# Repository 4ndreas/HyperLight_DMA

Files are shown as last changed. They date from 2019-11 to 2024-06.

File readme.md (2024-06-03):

# Hyperlight LED Driver
STM32F407 based WS2811/12 Led driver with 16-channel DMA output

## variant 
* added custom variant with DMA interrupt function

## patched libraies are
* Artnet
* Ethernet
	* Changed SPI speed
	* Port so 2 with increases the buffer in the W5500 chip per port to 8k
* Adafruit_SSD1306
	* Display size to 128x64
	
* Overrides for ST SPI Hal Code beed as compile options: -include "<absolute-src-path>/make_weak.h"

## ToDo

* Improvement for
    * better bit sorting
    * setLED function
    * setSnakeLED
    * better solution for other color modes

* Webserver Config for
    * Color Mode
    * offset 
    * Snake Wireing
    * FPS Counter

* USB test
* SD-Card 
* better Webserver with SD card or the website.h methode
* DMX out

## How to Install

```
https://github.com/stm32duino/BoardManagerFiles/raw/master/STM32/package_stm_index.json
```

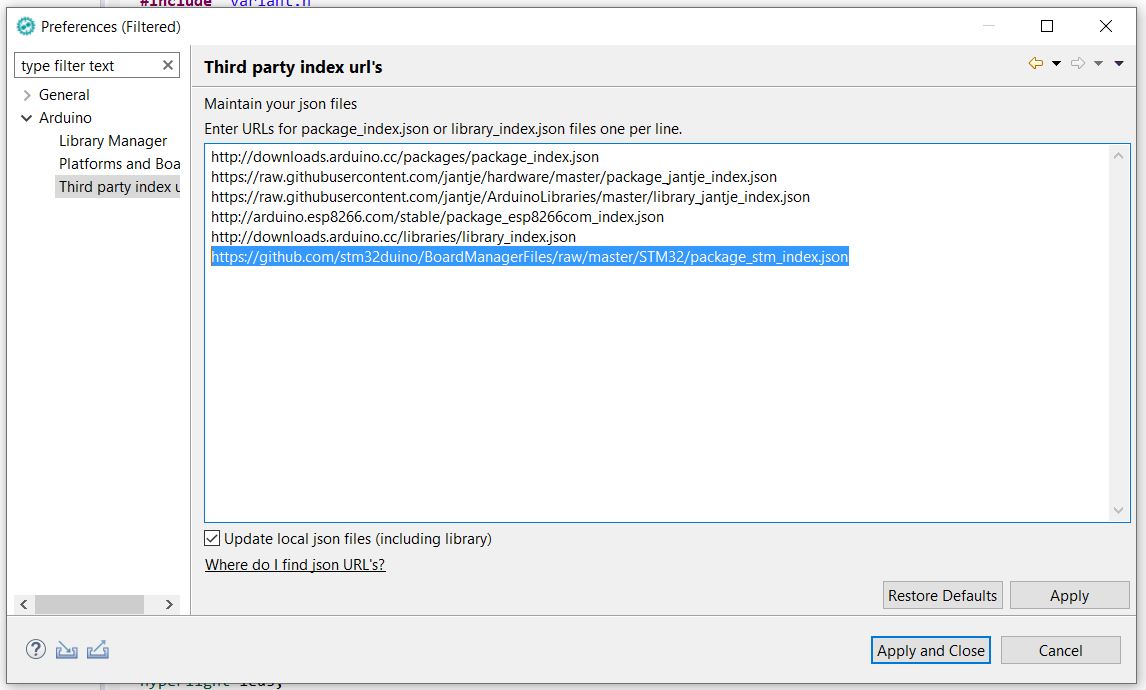
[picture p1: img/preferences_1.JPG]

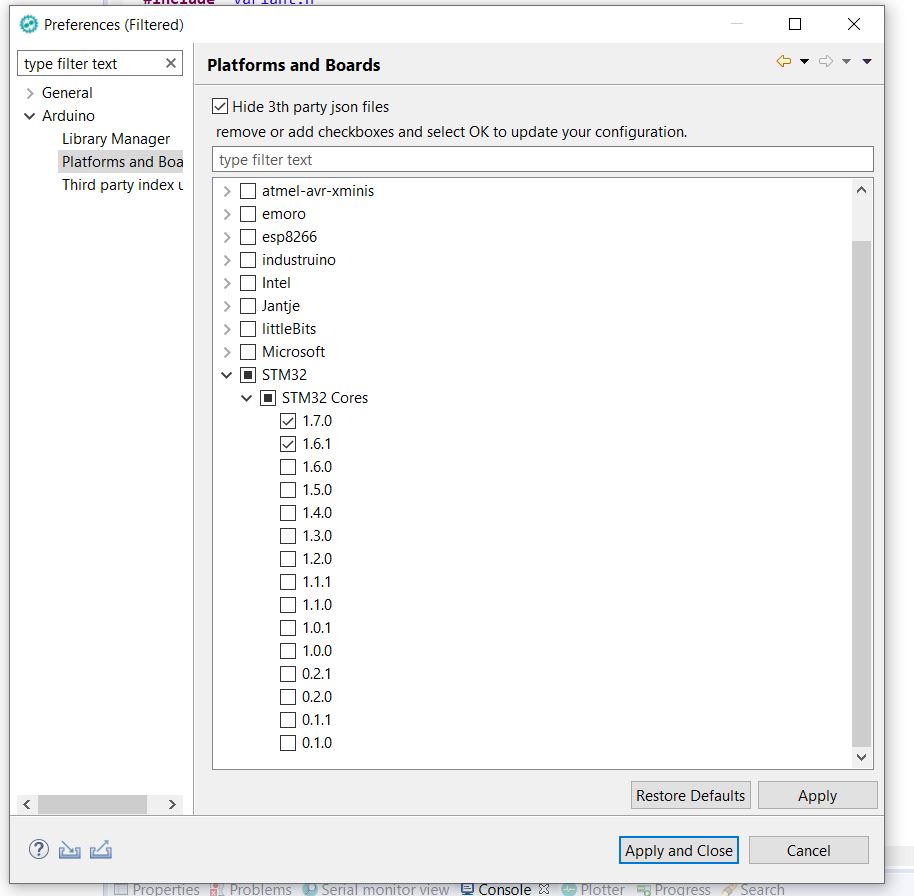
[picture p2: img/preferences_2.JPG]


### Adding a new board variant 

Path to the boards:

coppy the variants\Hyperlight folder in the package dir:

```
\Sloeber\arduinoPlugin\packages\STM32\hardware\stm32\1.7.0\variants\Hyperlight
```
or if the plain arduino IDE is used in  
```
.user\AppData\Local\Arduino15\packages\STM32\hardware\stm32\1.7.0\variants
```

Setting for the board:

Optimize: "Smallest(-Os default)"

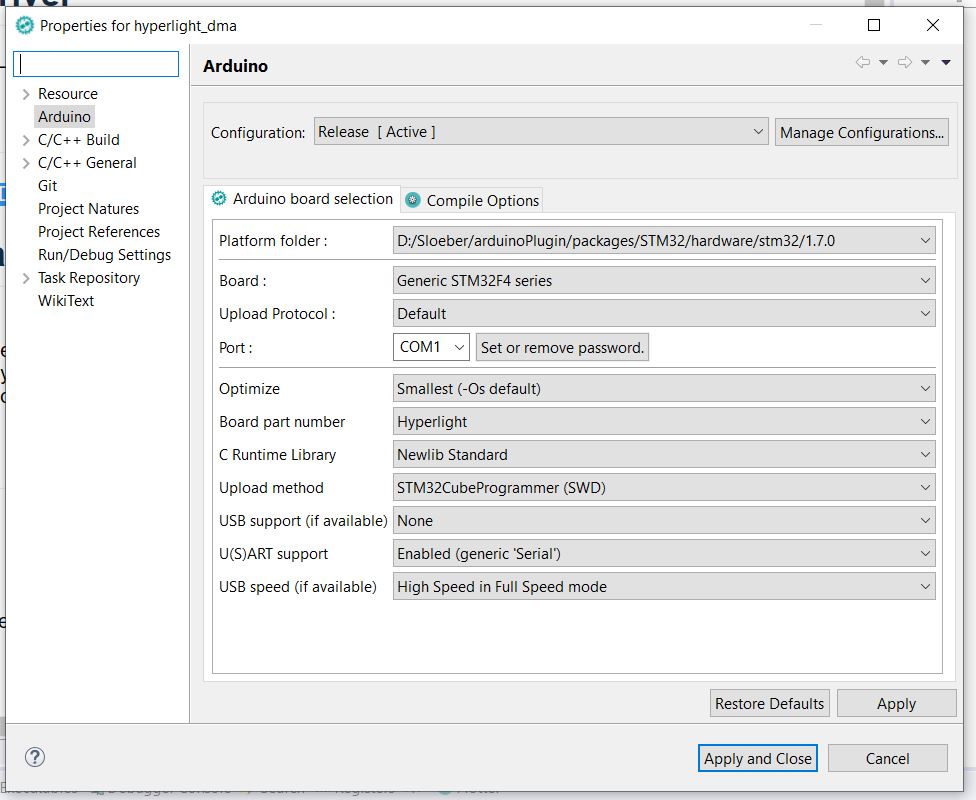
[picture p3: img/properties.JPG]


Add make_weak to "compiler Options"
```
-include "C:\Users\ahoel\Documents\sloeber-workspace\hyperlight_dma\make_weak.h"
```
![alt text][properties2]

### How to Debug
See the wiki form the STM32 Core
https://github.com/stm32duino/wiki/wiki/How-to-debug

Download sloeber-IDE form 
http://eclipse.baeyens.it/index.shtml

Change Target to:
```
-s "${openocd_path}/../scripts" -f interface/stlink-v2-1.cfg -f target/stm32f4x.cfg
```
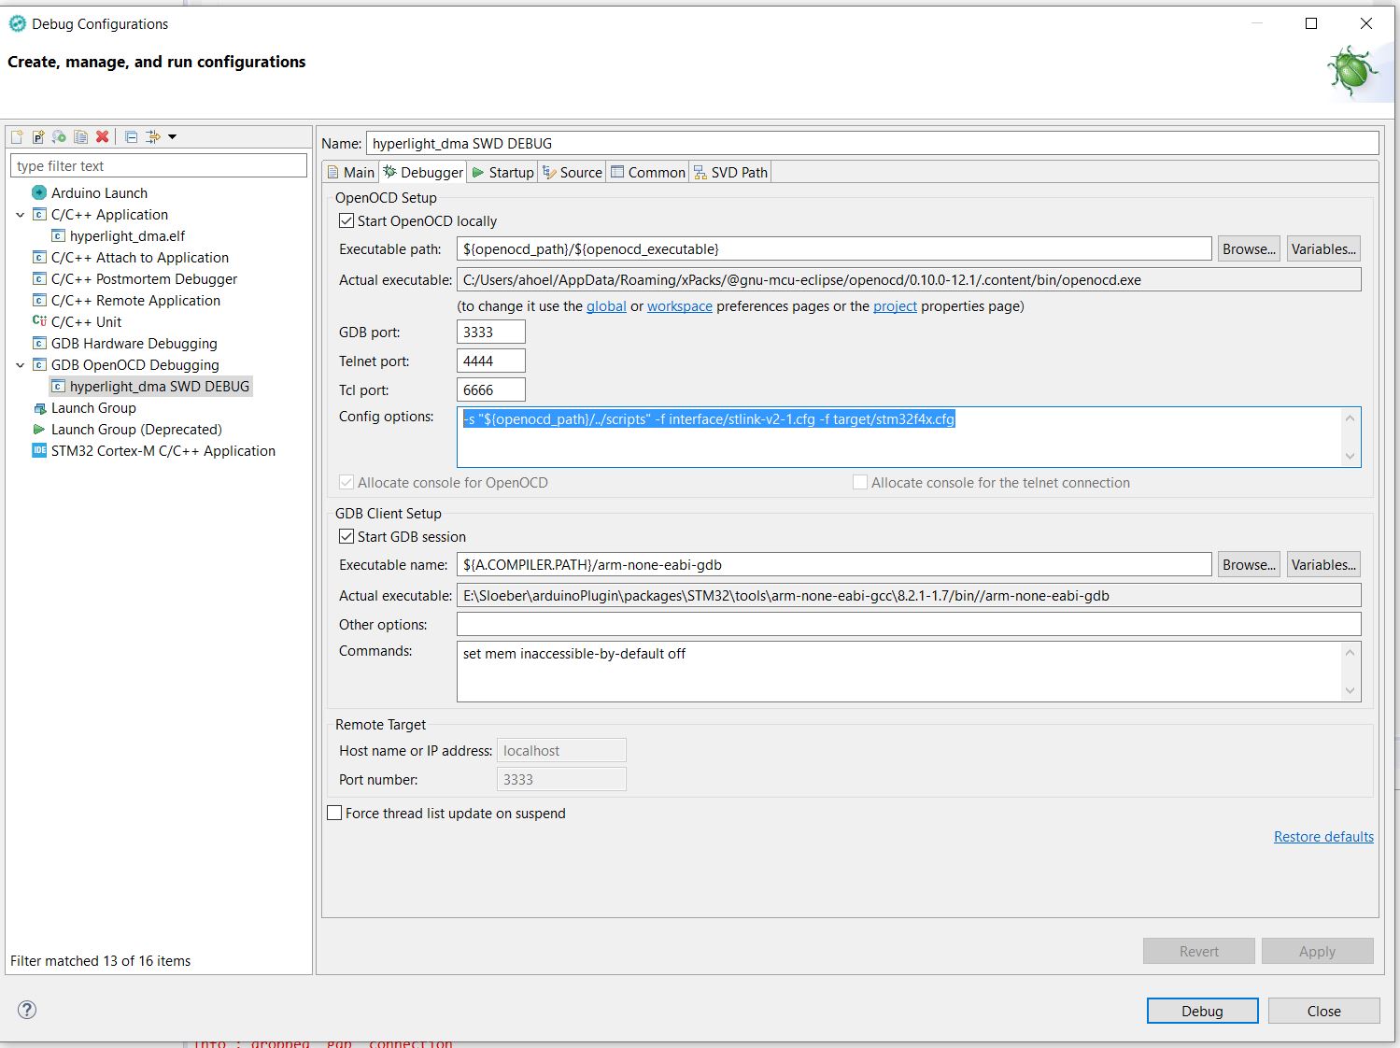
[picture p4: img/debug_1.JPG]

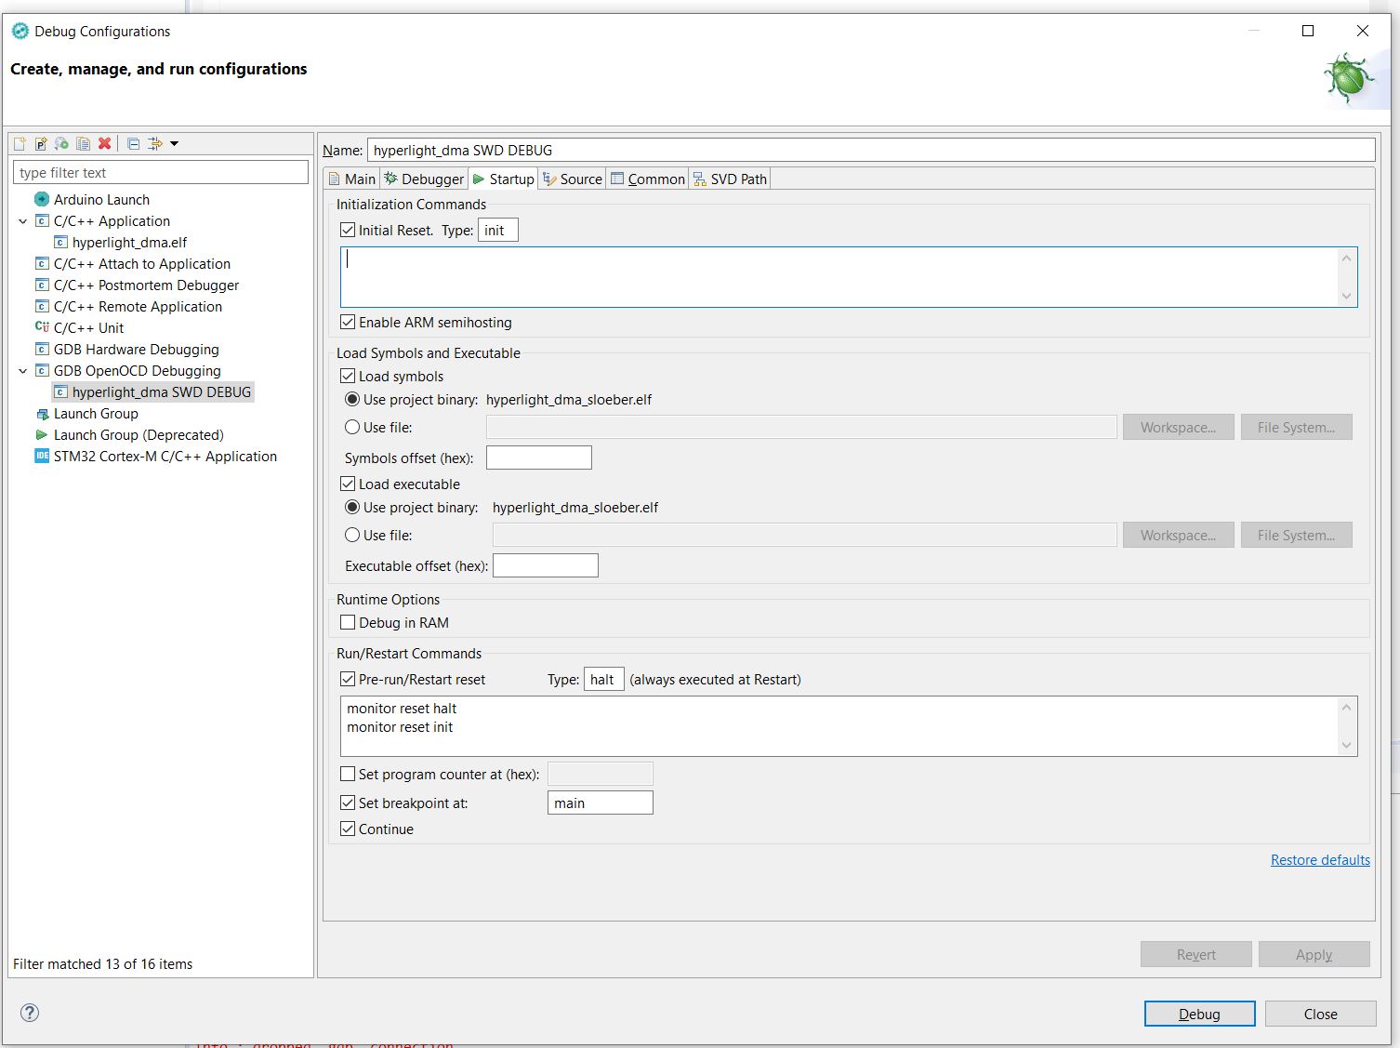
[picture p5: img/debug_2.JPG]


[preferences1]: img/preferences_1.JPG "Settings URL for STM32Core"
[preferences2]: img/preferences_2.JPG "Settings URL for STM32Core"
[properties]: img/properties.JPG "properties of the arduino ide"
[debug1]: img/debug_1.JPG "Settings URL for OCD Debugging"
[debug2]: img/debug_2.JPG "Settings URL for OCD Debugging"

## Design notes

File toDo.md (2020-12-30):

## ToDos

- optimiertes paralleles setzen von allen strips gleichzeitig
- SPI recieve code durchgehen ob optimieren

### Knownn Bugs

- packet los bei % 2 frame bei 255
-- mögliches problem mit nur beil 1 bit setzten effekt
-- maximaler zyklus für Bit sort setzten

### Nice to have

- Webserver wieder einbauen 
- Interrupt leitung Ethernet script.
- Profiling mit Artnet Sequenz number.
- oled display updaten.
- Testpattern zum geräte testen.

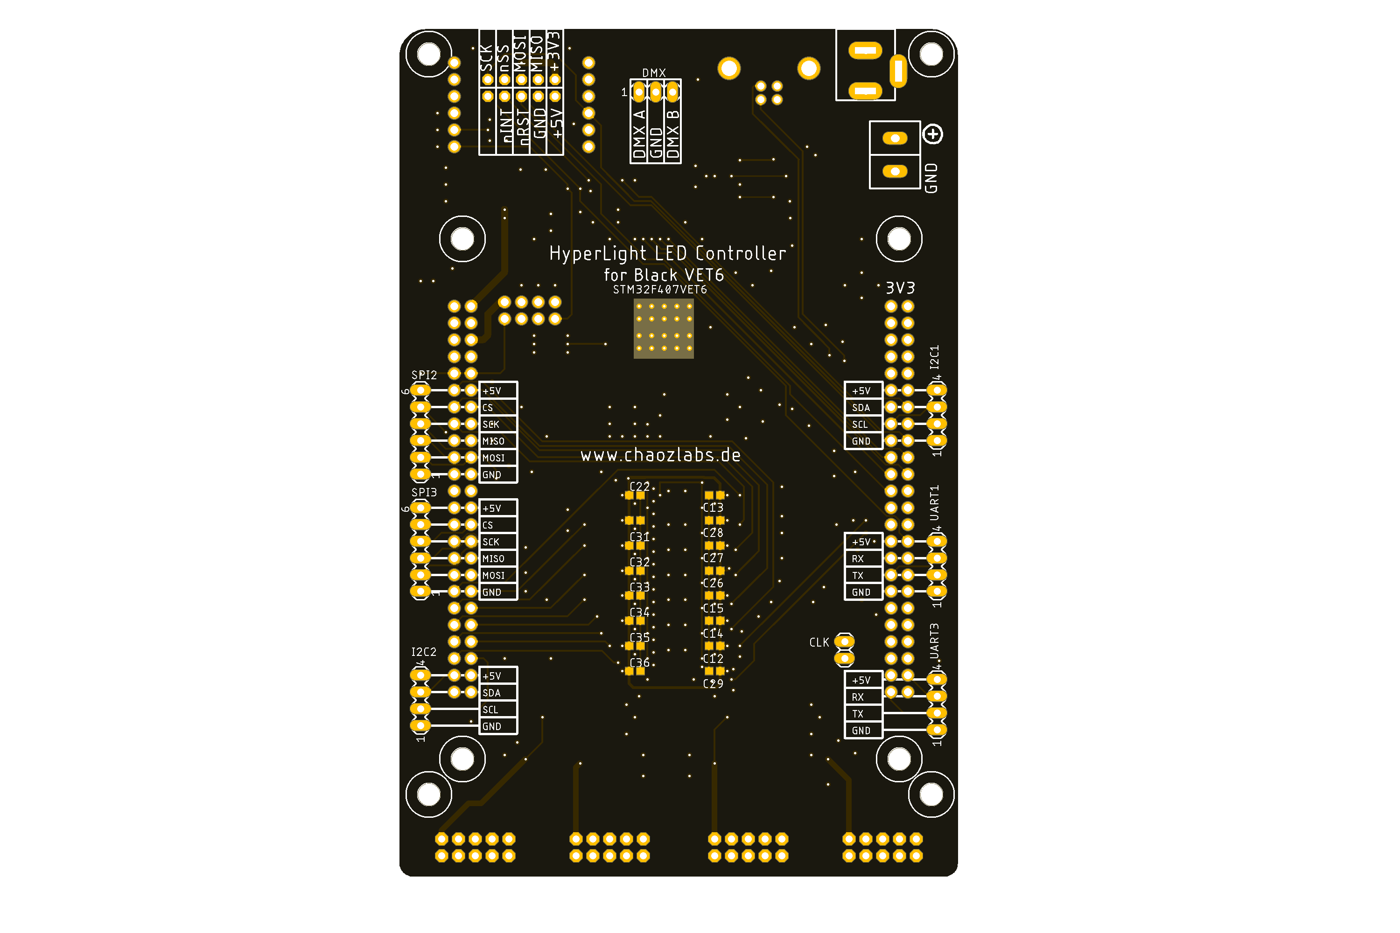
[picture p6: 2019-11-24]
hardware/rev1/HyperLight_S_rev1.0_Bottom.png

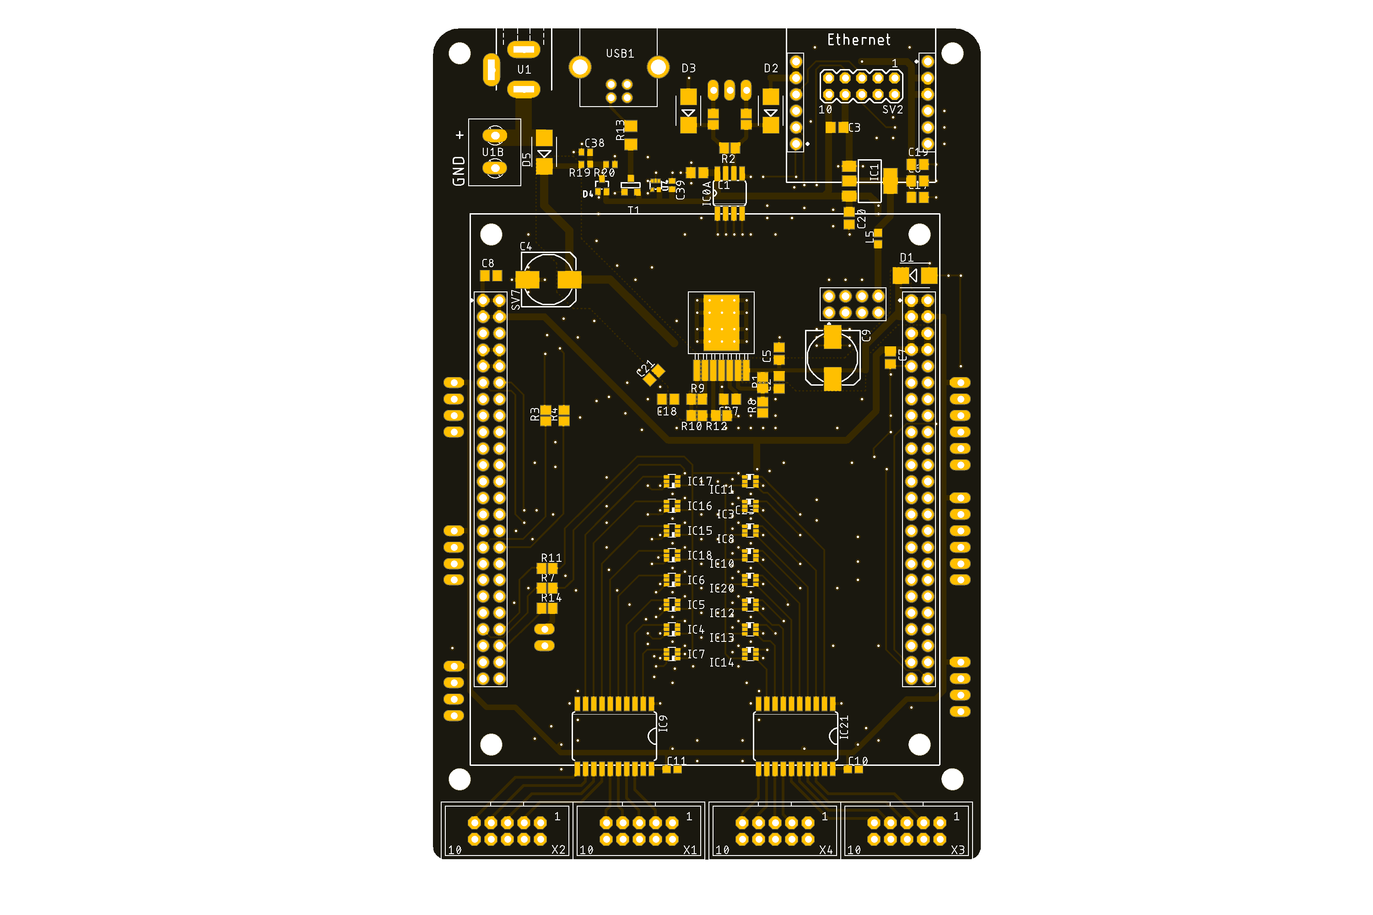
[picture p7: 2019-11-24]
hardware/rev1/HyperLight_S_rev1.0_Top.png

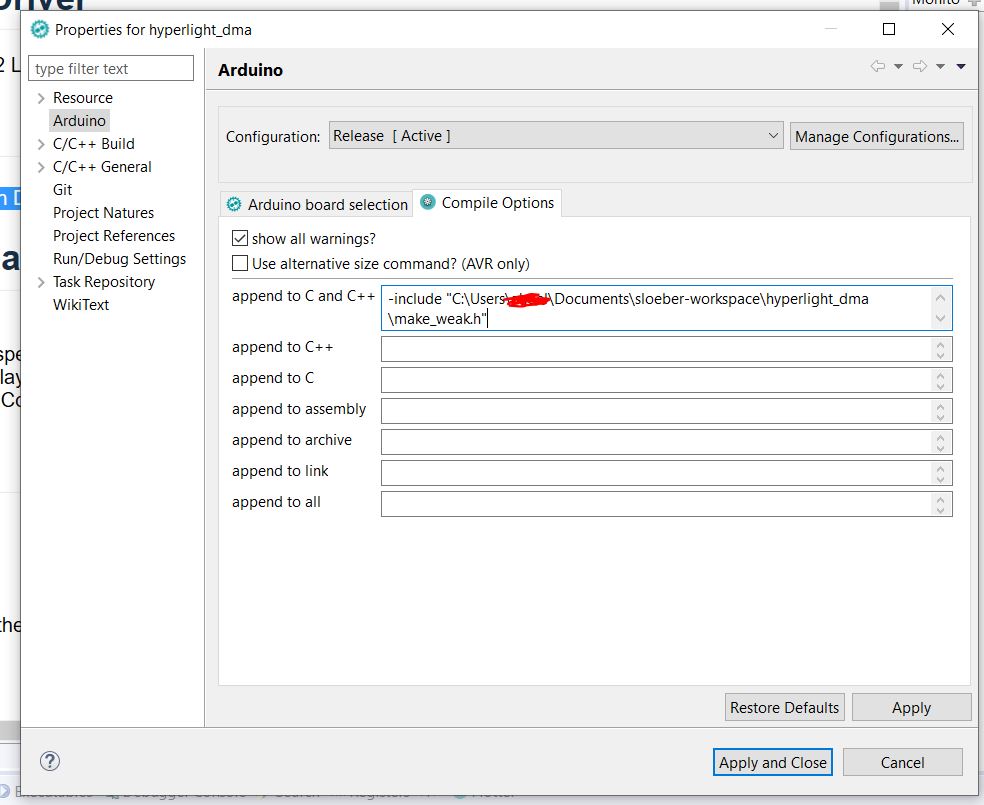
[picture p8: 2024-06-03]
img/properties2.JPG

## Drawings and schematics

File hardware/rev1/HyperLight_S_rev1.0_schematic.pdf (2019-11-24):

# GND ⁺³V³

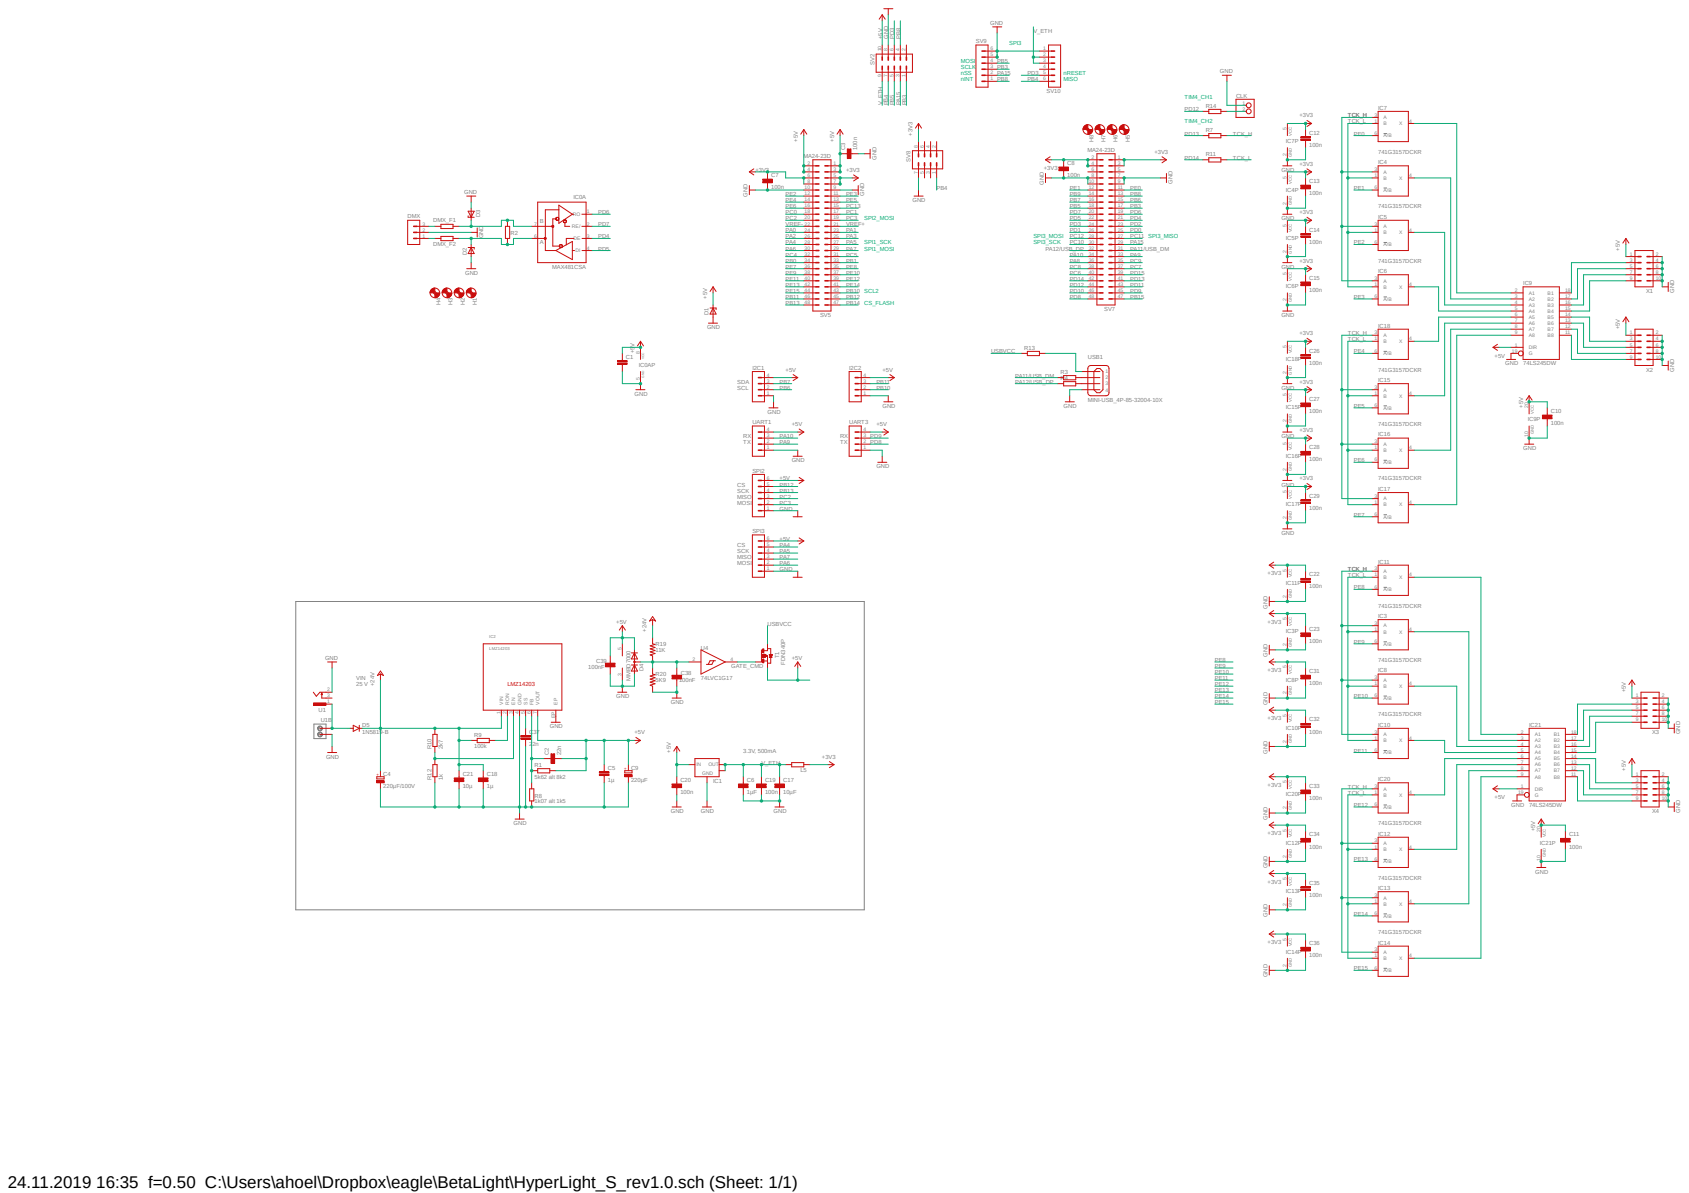
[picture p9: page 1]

IC7 2 5 GND VCC IC7P 2 5 GND VCC IC4P 2 5 GND VCC IC5P 2 5 GND VCC IC6P

GND
IC18 2 5 GND VCC IC18P 2 5 GND VCC IC15P 2 5 GND VCC IC16P 2 5 GND VCC IC17P

IC20 ² ⁵ GND VCC IC11P 2 5 GND VCC IC3P 2 5 GND VCC IC8P 2 5 GND VCC IC10P 2 5 GND VCC IC20P 2 5 GND VCC IC12P 2 5 GND VCC IC13P 2 5 GND VCC IC14P
100n GND GND GND GND GND GND GND GND +3V3

24.11.2019 16:35 f=0.50 C:\Users\ahoel\Dropbox\eagle\BetaLight\HyperLight_S_rev1.0.sch (Sheet: 1/1)

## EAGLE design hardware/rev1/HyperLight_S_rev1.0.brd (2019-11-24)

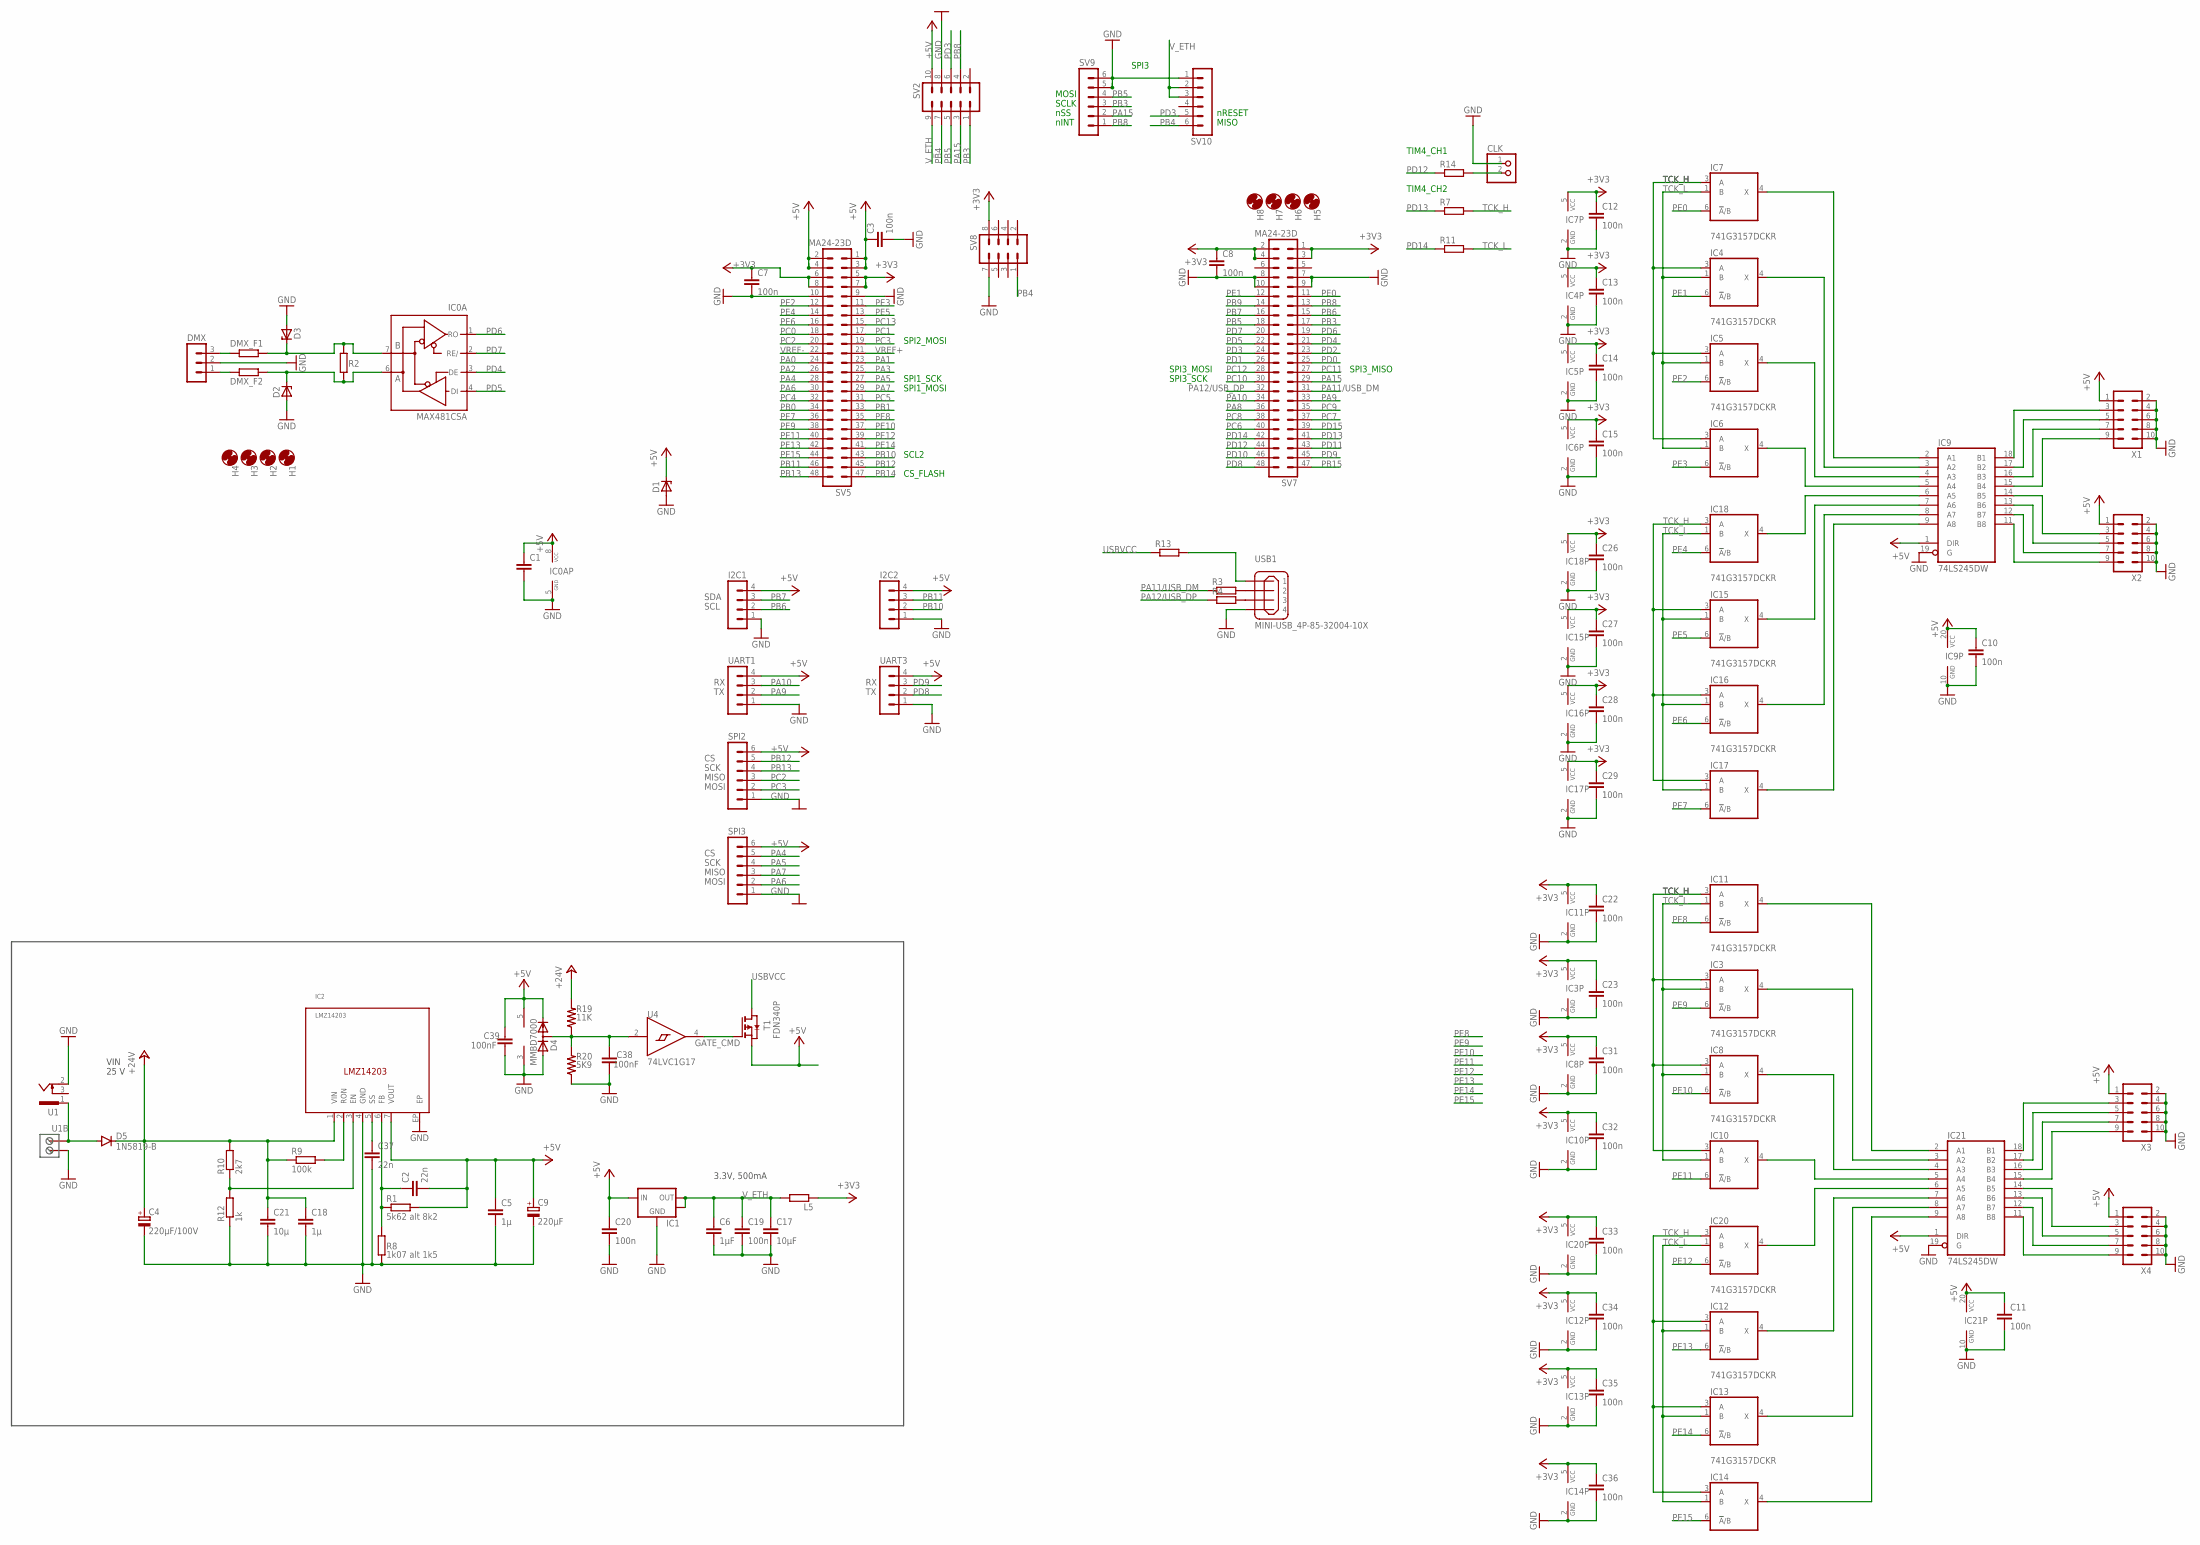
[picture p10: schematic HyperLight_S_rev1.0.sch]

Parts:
C1: C-EUC0805; C0805
C2, C37: 22n; C0805
C3, C7, C8, C19, C20: 100n; C0805
C4: 220µF/100V; 153CLV-0810
C5, C18: 1µ; C0805
C6: 1µF; C0805
C9: 220µF; 153CLV-0810
C10, C11, C12, C13, C14, C15, C22, C23, C26, C27, C28, C29, C31, C32, C33, C34, C35, C36: 100n; C0603
C17: 10µF; C0805
C21: 10µ; C0805
C38, C39: 100nF; C0402
CLK: PINHD-1X2; 1X02
D1, D2, D3: ZENER-DIODESMB; SMB
D4: MMBD7000; SC70-3-R
D5: 1N5819-B; SMB
DMX: MA03-1
DMX_F1, DMX_F2: R-EU_R0805; R0805
H1, H2, H3, H4, H5, H6, H7, H8: MOUNT-HOLE3.2; 3,2
I2C1, I2C2: MA04-1
IC0A: MAX481CSA; SO08
IC1: LM1117; SOT223
IC2: LMZ14203; TO-PMOD
IC3, IC4, IC5, IC6, IC7, IC8, IC10, IC11, IC12, IC13, IC14, IC15, IC16, IC17, IC18, IC20: 741G3157DCKR; DCK_R-PDSO-G6
IC9, IC21: 74LS245DW; SO20W
L5: R-EU_R0603; R0603
R1: 5k62 alt 8k2; R0805
R2, R3, R4, R7, R11, R14: R-EU_R0805; R0805
R8: 1k07 alt 1k5; R0805
R9: 100k; R0805
R10: 2k7; R0805
R12: 1k; R0805
R13: R-EU_R1206; R1206
R19: 11K; R0402
R20: 5K9; R0402
SPI2, SPI3: MA06-1
SV2: MA05-2
SV5, SV7: MA24-23D; HDRVR48W64P254_2X24_6096X508X762B
SV8: MA04-2MALE_3D; HDRV8W64P254_2X4_1016X508X838B
SV9, SV10: MA06-1FEMALE_3D; HDRVR6W64P254_1X6_1524X254X762B
T1: FDN340P; SOT-23
U1: 733980-62
U1B: RIACON101-02
U4: 74LVC1G17; SOT-553
UART1, UART3: MA04-1
USB1: MINI-USB_4P-85-32004-10X; 85-32004-10X
X1, X2, X3, X4: MA05-2MA05-2S; MA05-2S

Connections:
+3V3: C7.1, C8.1, C12.1, C13.1, C14.1, C15.1, C22.1, C23.1, C26.1, C27.1, C28.1, C29.1, C31.1, C32.1, C33.1, C34.1, C35.1, C36.1, IC3.5 (VCC), IC4.5 (VCC), IC5.5 (VCC), IC6.5 (VCC), IC7.5 (VCC), IC8.5 (VCC), IC10.5 (VCC), IC11.5 (VCC), IC12.5 (VCC), IC13.5 (VCC), IC14.5 (VCC), IC15.5 (VCC), IC16.5 (VCC), IC17.5 (VCC), IC18.5 (VCC), IC20.5 (VCC), L5.1, SV5.5, SV5.6, SV5.7, SV5.8, SV7.1, SV7.2, SV7.3, SV7.4, SV8.8
+5V: C1.1, C2.2, C3.1, C5.1, C9.+, C10.1, C11.1, C20.1, C39.2, D1.C, D4.2 (C), I2C1.4, I2C2.4, IC0A.8 (VCC), IC1.3 (IN), IC2.7 (VOUT), IC9.1 (DIR), IC9.20 (VCC), IC21.1 (DIR), IC21.20 (VCC), R1.2, SPI2.6, SPI3.6, SV2.10, SV5.1, SV5.2, SV5.3, SV5.4, T1.2 (S), U4.5 (VCC), UART1.4, UART3.4, X1.1, X2.1, X3.1, X4.1
+24V: C4.+, C18.1, C21.1, D5.C, IC2.1 (VIN), R9.1, R10.2, R19.2
CMP: C38.2, D4.3 (AC), R19.1, R20.2, U4.2 (A)
GATE_CMD: T1.3 (G), U4.4 (Y)
GND: C1.2, C3.2, C4.-, C5.2, C6.2, C7.2, C8.2, C9.-, C10.2, C11.2, C12.2, C13.2, C14.2, C15.2, C17.2, C18.2, C19.2, C20.2, C21.2, C22.2, C23.2, C26.2, C27.2, C28.2, C29.2, C31.2, C32.2, C33.2, C34.2, C35.2, C36.2, C37.2, C38.1, C39.1, CLK.1, D1.A, D2.A, D3.A, D4.1 (A), DMX.2, I2C1.1, I2C2.1, IC0A.5 (GND), IC1.1 (GND), IC2.4 (GND), IC2.EP, IC3.2 (GND), IC4.2 (GND), IC5.2 (GND), IC6.2 (GND), IC7.2 (GND), IC8.2 (GND), IC9.10 (GND), IC9.19 (G), IC10.2 (GND), IC11.2 (GND), IC12.2 (GND), IC13.2 (GND), IC14.2 (GND), IC15.2 (GND), IC16.2 (GND), IC17.2 (GND), IC18.2 (GND), IC20.2 (GND), IC21.10 (GND), IC21.19 (G), R8.1, R12.1, R20.1, SPI2.1, SPI3.1, SV2.8, SV5.9, SV5.10, SV7.7, SV7.8, SV7.9, SV7.10, SV8.7, SV9.5, SV9.6, SV10.1, U1.2, U1B.P$2, U4.3 (GND), UART1.1, UART3.1, USB1.4, X1.2, X1.4, X1.6, X1.8, X1.10, X2.2, X2.4, X2.6, X2.8, X2.10, X3.2, X3.4, X3.6, X3.8, X3.10, X4.2, X4.4, X4.6, X4.8, X4.10
unnamed: IC7.4 (X), IC9.2 (A1)
unnamed: IC5.4 (X), IC9.4 (A3)
unnamed: R3.2, USB1.2
unnamed: IC6.4 (X), IC9.5 (A4)
unnamed: IC4.4 (X), IC9.3 (A2)
unnamed: IC9.18 (B1), X1.3
unnamed: D3.C, DMX_F1.1, IC0A.7 (B), R2.2
unnamed: D2.C, DMX_F2.1, IC0A.6 (A), R2.1
unnamed: R4.2, USB1.3
unnamed: C2.1, IC2.6 (FB), R1.1, R8.2
unnamed: IC9.6 (A5), IC18.4 (X)
unnamed: IC2.2 (RON), R9.2
unnamed: IC11.4 (X), IC21.2 (A1)
unnamed: C37.1, IC2.5 (SS)
unnamed: IC9.9 (A8), IC17.4 (X)
unnamed: IC2.3 (EN), R10.1, R12.2
unnamed: D5.A, U1.1, U1B.P$1
unnamed: IC9.8 (A7), IC16.4 (X)
unnamed: IC9.7 (A6), IC15.4 (X)
unnamed: IC9.17 (B2), X1.5
unnamed: IC9.16 (B3), X1.7
unnamed: IC9.15 (B4), X1.9
unnamed: DMX.3, DMX_F1.2
unnamed: DMX.1, DMX_F2.2
unnamed: IC8.4 (X), IC21.4 (A3)
unnamed: IC10.4 (X), IC21.5 (A4)
unnamed: IC20.4 (X), IC21.6 (A5)
unnamed: IC14.4 (X), IC21.9 (A8)
unnamed: IC13.4 (X), IC21.8 (A7)
unnamed: IC12.4 (X), IC21.7 (A6)
unnamed: IC3.4 (X), IC21.3 (A2)
unnamed: R13.2, USB1.1
unnamed: CLK.2, R14.2
unnamed: IC21.18 (B1), X3.3
unnamed: IC21.17 (B2), X3.5
unnamed: IC21.16 (B3), X3.7
unnamed: IC21.15 (B4), X3.9
unnamed: IC21.14 (B5), X4.3
unnamed: IC21.13 (B6), X4.5
unnamed: IC21.12 (B7), X4.7
unnamed: IC21.11 (B8), X4.9
unnamed: IC9.14 (B5), X2.3
unnamed: IC9.13 (B6), X2.5
unnamed: IC9.12 (B7), X2.7
unnamed: IC9.11 (B8), X2.9
PA0: SV5.24
PA1: SV5.23
PA2: SV5.26
PA3: SV5.25
PA4: SPI3.5, SV5.28
PA5: SPI3.4, SV5.27
PA6: SPI3.2, SV5.30
PA7: SPI3.3, SV5.29
PA8: SV7.36
PA9: SV7.33, UART1.2
PA10: SV7.34, UART1.3
PA11/USB_DM: R3.1, SV7.31
PA12/USB_DP: R4.1, SV7.32
PA15: SV2.3, SV7.29, SV9.2
PB0: SV5.34
PB1: SV5.33
PB3: SV2.1, SV7.17, SV9.3
PB4: SV2.7, SV8.1, SV10.6
PB5: SV2.5, SV7.18, SV9.4
PB6: I2C1.2, SV7.15
PB7: I2C1.3, SV7.16
PB8: SV2.4, SV7.13, SV9.1
PB9: SV7.14
PB10: I2C2.2, SV5.43
PB11: I2C2.3, SV5.46
PB12: SPI2.5, SV5.45
PB13: SPI2.4, SV5.48
PB14: SV5.47
PB15: SV7.47
PC0: SV5.18
PC1: SV5.17
PC2: SPI2.3, SV5.20
PC3: SPI2.2, SV5.19
PC4: SV5.32
PC5: SV5.31
PC6: SV7.40
PC7: SV7.37
PC8: SV7.38
PC9: SV7.35
PC10: SV7.30
PC11: SV7.27
PC12: SV7.28
PC13: SV5.15
PD0: SV7.25
PD1: SV7.26
PD2: SV7.23
PD3: SV2.6, SV7.24, SV10.5
PD4: IC0A.3 (DE), SV7.21
PD5: IC0A.4 (DI), SV7.22
PD6: IC0A.1 (RO), SV7.19
PD7: IC0A.2 (RE/), SV7.20
PD8: SV7.48, UART3.2
PD9: SV7.45, UART3.3
PD10: SV7.46
PD11: SV7.43
PD12: R14.1, SV7.44
PD13: R7.1, SV7.41
PD14: R11.1, SV7.42
PD15: SV7.39
PE0: IC7.6 (!A!/B), SV7.11
PE1: IC4.6 (!A!/B), SV7.12
PE2: IC5.6 (!A!/B), SV5.12
PE3: IC6.6 (!A!/B), SV5.11
PE4: IC18.6 (!A!/B), SV5.14
PE5: IC15.6 (!A!/B), SV5.13
PE6: IC16.6 (!A!/B), SV5.16
PE7: IC17.6 (!A!/B), SV5.36
PE8: IC11.6 (!A!/B), SV5.35
PE9: IC3.6 (!A!/B), SV5.38
PE10: IC8.6 (!A!/B), SV5.37
PE11: IC10.6 (!A!/B), SV5.40
PE12: IC20.6 (!A!/B), SV5.39
PE13: IC12.6 (!A!/B), SV5.42
PE14: IC13.6 (!A!/B), SV5.41
PE15: IC14.6 (!A!/B), SV5.44
TCK_H: IC3.3 (A), IC4.3 (A), IC5.3 (A), IC6.3 (A), IC7.3 (A), IC8.3 (A), IC10.3 (A), IC11.3 (A), IC12.3 (A), IC13.3 (A), IC14.3 (A), IC15.3 (A), IC16.3 (A), IC17.3 (A), IC18.3 (A), IC20.3 (A), R7.2
TCK_L: IC3.1 (B), IC4.1 (B), IC5.1 (B), IC6.1 (B), IC7.1 (B), IC8.1 (B), IC10.1 (B), IC11.1 (B), IC12.1 (B), IC13.1 (B), IC14.1 (B), IC15.1 (B), IC16.1 (B), IC17.1 (B), IC18.1 (B), IC20.1 (B), R11.2
USBVCC: R13.1, T1.1 (D)
VREF+: SV5.21
VREF-: SV5.22
V_ETH: C6.1, C17.1, C19.1, IC1.2 (OUT), IC1.4 (PAD), L5.2, SV2.9, SV10.2, SV10.3

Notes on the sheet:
MOSI
SCLK
nSS
nINT
nRESET
MISO
SPI1_MOSI
SPI1_SCK
SPI3_SCK
SPI3_MOSI
SPI3_MISO
SPI2_MOSI
SCL2
CS_FLASH
SPI3
TIM4_CH1
TIM4_CH2
25 V
VIN
3.3V, 500mA
SDA
SCL
SCK

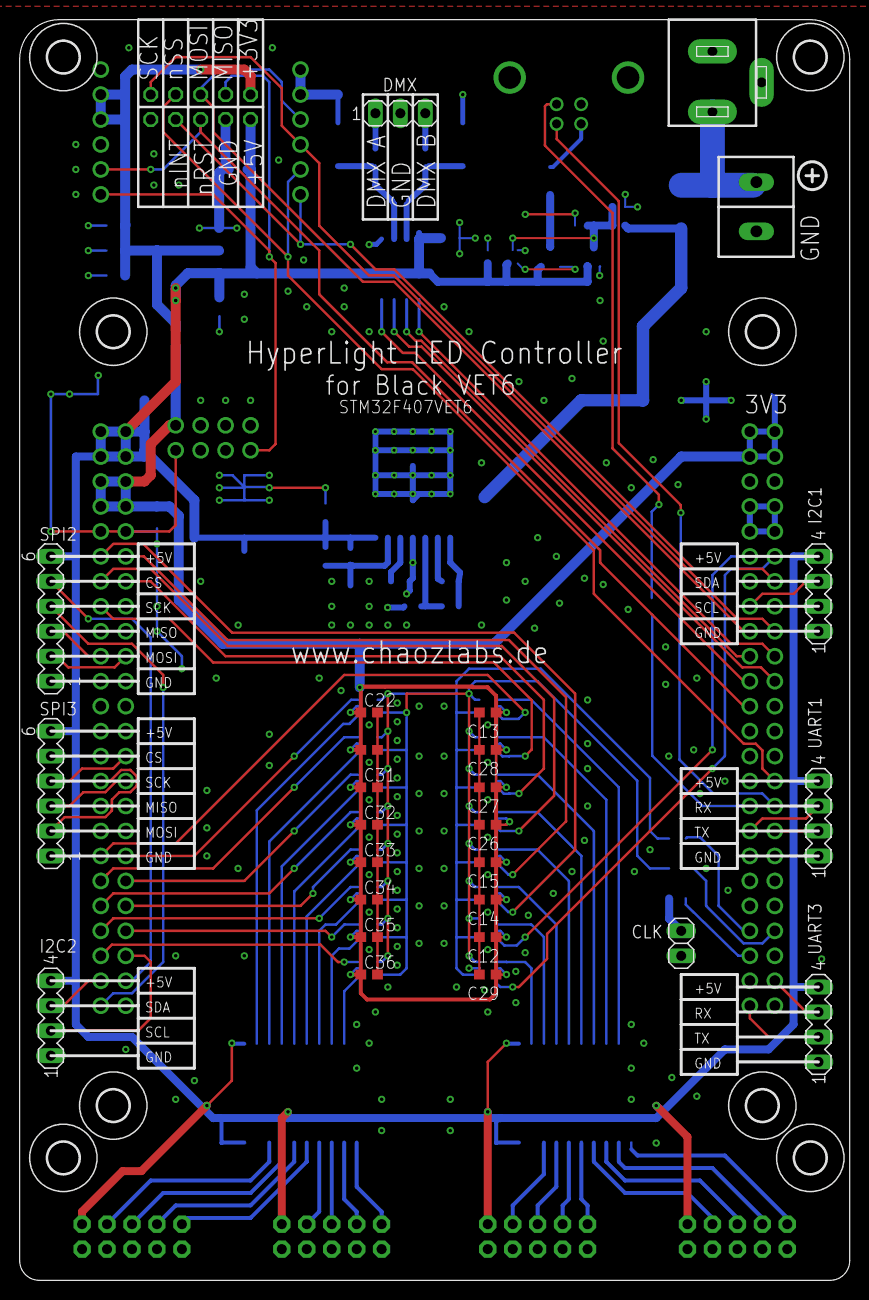
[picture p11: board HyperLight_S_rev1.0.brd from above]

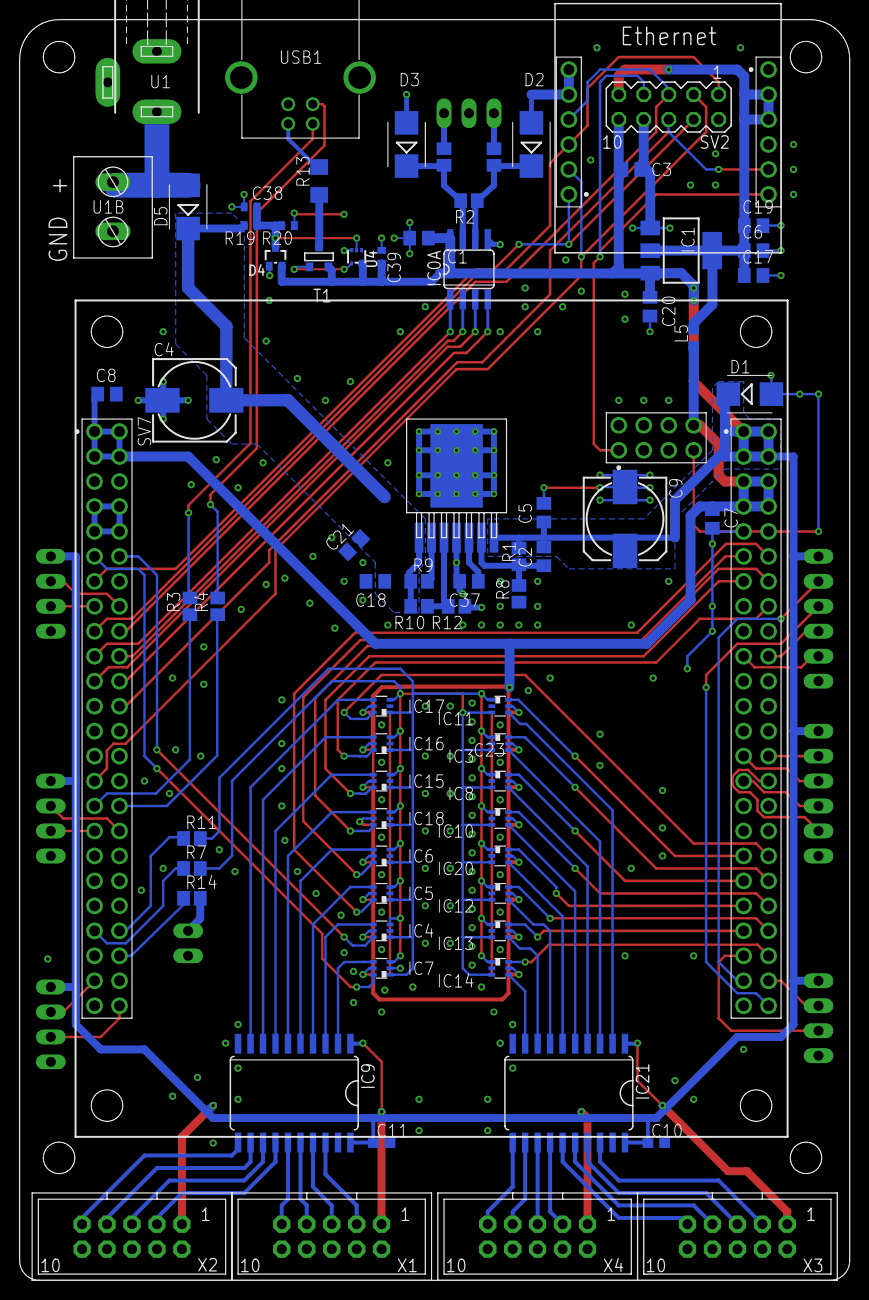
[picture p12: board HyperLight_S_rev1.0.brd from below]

Board: 2 copper layers, 84.5 x 128.3 mm, 109 parts (77 on the bottom side), 102 nets.

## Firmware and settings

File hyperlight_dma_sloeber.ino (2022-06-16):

#define ARCH_STM32

#include "Arduino.h"
#include "variant.h"
#include "pin_config.h"
#include <SPI.h>
#include <SPIMemory.h>
#include <IWatchdog.h>
#include <FlashStorage_STM32.h>
#include <Math.h>
#include "BufferedArtnet.h"
#include "hyperlight.h"
#include "F4DMXSerial.h"
#include "helper.h"


//#define USE_WEBSERVER
#define USE_OLED
#define USE_BUTTONS
#define USE_DMX
//#define USE_LCD
//#define USE_FLASH
#define USE_EEPROM
//#define USE_WATCHDOG


#define IP_ENDING 22


#ifdef USE_DMX
// To do
#define DMX_UNI 65
F4DMXSerial dmxOUT;
#endif

#ifdef USE_BUTTONS
// Button1
// Button2
#endif

#ifdef USE_OLED
#include <Wire.h>
#include <Adafruit_GFX.h>
#include <Adafruit_SSD1306.h>
#include <Fonts/FreeSansBold9pt7b.h>
#define OLED_RESET -1
Adafruit_SSD1306 display(OLED_RESET);
#endif


#ifdef USE_LCD
#include <wire.h>
//#include <liquidcrystal_i2c.h>
#include <LiquidCrystal_I2C.h>
// Set the LCD address to 0x27 for a 16 chars and 2 line display
LiquidCrystal_I2C lcd(0x27, 16, 2);
#endif


#ifdef USE_WEBSERVER
#include "website.h"

// Initialize the Ethernet server library
EthernetServer server(80);
#endif

struct sConfig sysConfig;

#ifdef USE_FLASH
	SPIFlash flash(SPI_FLASH_CS);
#endif




#define CONFIG_UNI 66
BufferedArtnet<67> artnet;
//BufferedArtnet<33> artnet;
hyperlight leds;

#define LED_OFFSET 1


byte ip[] = {10, 39, 0, IP_ENDING};
#define CONCAT(m, n) m ## n
#define HEXIFY(x) CONCAT(0x, x)
byte mac[] = {0x04, 0xE9, 0xE5, HEXIFY(IP_ENDING), 0x69, 0xEC};

// sets artnet timeout in ms (only for show)
#define INACTIVITY_TIMEOUT 1000
IPAddress remoteArd;

void setup() {

#ifdef USE_WATCHDOGUSE_WATCHDOG
  if (IWatchdog.isReset(true)) {
		  // to do monitor resets by watchdog
  }

  IWatchdog.begin(4000000);
#endif

  // Hardware Serial1 for debug out
  Serial.begin(115200);
  Serial.println("init");

  Serial.println("My IP:");
  Serial.print(ip[0], DEC);Serial.print(".");
  Serial.print(ip[1], DEC);Serial.print(".");
  Serial.print(ip[2], DEC);Serial.print(".");
  Serial.print(ip[3], DEC);Serial.println("");

  leds.begin();



#ifdef USE_WEBSERVER
  server.begin();
#endif

#ifdef USE_OLED

  Wire.setSDA(I2C1_SDA_PIN);
  Wire.setSCL(I2C1_SCL_PIN);


  display.begin(SSD1306_SWITCHCAPVCC, 0x3C);  // initialize with the I2C addr 0x3D (for the 128x64)
  // init done
  display.clearDisplay();
  updateDisplay();
#endif


#ifdef USE_LCD

  Wire.setSDA(I2C1_SDA_PIN);
  Wire.setSCL(I2C1_SCL_PIN);
  lcd.begin(16,2);
  lcd.init();
  lcd.backlight();
  lcd.clear();


  lcd.setCursor(0, 0);
  lcd.print("Hyperlight");
  lcd.setCursor(0, 1);
  lcd.print("init");
  lcd.display();

#endif


#ifdef USE_DMX
  dmxOUT.begin();
  delay(1);
  dmxOUT.Send_Packet();
#endif

#ifdef USE_FLASH
  flash.begin();
  readConfig();
#endif

#ifdef USE_EEPROM
  //Serial.print(F("\nStart FlashStoreAndRetrieve on ")); Serial.println(BOARD_NAME);
  Serial.println(FLASH_STORAGE_STM32_VERSION);

  Serial.print("EEPROM length: ");
  Serial.println(EEPROM.length());

  readConfig();

#else
  defaultConfig();
#endif


  pinMode(ETH_RST_PIN, OUTPUT);

  digitalWrite(ETH_RST_PIN, HIGH);
  delay(100);
  digitalWrite(ETH_RST_PIN, LOW);
  delay(100);
  digitalWrite(ETH_RST_PIN, HIGH);
  delay(100);

  SPI.setMISO(ETH_MISO_PIN);
  SPI.setMOSI(ETH_MOSI_PIN);
  SPI.setSCLK(ETH_SCK_PIN);
  Ethernet.init(ETH_SCS_PIN);
  Ethernet.begin(mac, ip);

  artnet.begin();



}

uint32_t last_update = 0;
uint32_t last_artnet_update = 0;
uint32_t last_dmx_update = 0;
uint32_t currentTime = 0;
unsigned long update_time = 0;

bool new_data = false;
bool new_dmx_data = false;
unsigned frames = 0;

void loop() {
	currentTime = millis();

#ifdef USE_DMX
	if(((currentTime - last_dmx_update) > (1000 / 30)) && new_dmx_data) // 30 fps dmx update
	{
		last_dmx_update = currentTime;
		dmxOUT.Send_Packet();
		new_dmx_data = false;
	}
#endif

	while(!(artnet.syncMode() && artnet.syncPending()) && artnet.read()) {
		new_data = true;
		last_artnet_update = currentTime;
	}

	if ((!artnet.syncMode() && new_data && ((currentTime - last_artnet_update) > 5 )) // heuristic update
	 || (artnet.syncMode() && artnet.syncPending())	)	// synchronized update
	{
		if(leds.isDMAIdle()){

			unsigned long conv_start = micros();
			for(unsigned c = 0; c < 16; c++) {
				//leds.setStripLED(c, artnet.getUniverseData(c*2), 510, 0, GRB);
				//leds.setStripLED(c, artnet.getUniverseData((c*2) + 1), 510, 170, GRB);

				// sysConfig.ledConfig[c].color

				if ( artnet.newUniverseData(c) > 0 )
					leds.setStripLED(c, artnet.getUniverseData(c), 510, 0, sysConfig.ledConfig[c].color);
				if ( artnet.newUniverseData(c + 16) > 0 )
					leds.setStripLED(c, artnet.getUniverseData((c) + 16), 510, 170, sysConfig.ledConfig[c].color);
				if ( artnet.newUniverseData(c + 32) > 0 )
					leds.setStripLED(c, artnet.getUniverseData((c) + 32), 510, 340, sysConfig.ledConfig[c].color);
				if ( artnet.newUniverseData(c + 48) > 0 )
					leds.setStripLED(c, artnet.getUniverseData((c) + 48), 510, 510, sysConfig.ledConfig[c].color);

#ifdef USE_DMX
				// To do
				if ( artnet.newUniverseData(DMX_UNI) > 0 )
				{
					uint8_t * data = artnet.getUniverseData(DMX_UNI);
					dmxOUT.write_block(1, data, 512);
					new_dmx_data = true;
				}
#endif
				if ( artnet.newUniverseData(CONFIG_UNI) > 0 )
				{
					// config universe
					uint8_t * data = artnet.getUniverseData(CONFIG_UNI);

					uint8_t magic = *data;
					uint8_t cmd = *(data +1);
					uint8_t channel = *(data +2);
					uint8_t offset = *(data +3);
					uint8_t color = *(data +4);

					//Serial.print(ip[3], DEC);Serial.println("");
					Serial.println("\r\ncondig packet");
					Serial.print("magic:");Serial.println(magic);
					Serial.print("cmd:");Serial.println(cmd);
					Serial.print("channel:");Serial.println(channel);
					Serial.print("offset:");Serial.println(offset);
					Serial.print("color:");Serial.println(color);

					if(magic == 42){
						if (cmd == 1)
						{
							// set offset and color
							if( channel < 16)
							{
								sysConfig.ledConfig[channel].offset = offset;
								sysConfig.ledConfig[channel].color = (colorMode)color;

								// set offset to hardware
								leds.setOffset(channel,offset);
							}
						}
						else if(cmd == 2)
						{
							// save config
							saveConfig();
						}
						else if(cmd == 3)
						{
							// default config
							defaultConfig();
						}
						else if(cmd == 4)
						{
							// read config config
							readConfig();
						}
						else if(cmd == 5)
						{
							// enable status LEDs
							Serial.println("set status LEDs\r\n");
							sysConfig.enOffsetLEDs = channel;
						}
						else if(cmd == 66)
						{
							// reset device
							Serial.println("reset Device\r\n");
							IWatchdog.begin(1000000);
							while(1)
							{
								;
							}
						}
					}
				}
			}

			long unsigned conv_time = micros() - conv_start;
			if(conv_time > update_time) {
				update_time = conv_time;
				conv_start = micros();
			}

			leds.show();

			new_data = false;

			frames++;

			if(frames % 10 == 0)
				update_time = 0;


			artnet.clearSyncPending();
		}

/*		if (currentTime - last_update > 30)	// 50 fps
		{
			last_update = currentTime;
		}*/
	}

	updateStatusLEDs();

#ifdef USE_WEBSERVER
	webserverLoop();
#endif
#ifdef USE_OLED
    updateDisplay();
#endif

#ifdef USE_LCD
  updateDisplay();
#endif

#ifdef USE_WATCHDOGUSE_WATCHDOG
  IWatchdog.reload();
#endif
}

void updateStatusLEDs(void)
{
	static uint32_t lastStatusUpdate = 0;
	if(( currentTime - lastStatusUpdate) > 1000){
		lastStatusUpdate = currentTime;

		int globalIdle = 0;
		// set status led
		for (int strip = 0; strip < 16; strip++) {
			uint32_t lastUpdate = currentTime - leds.getUpdateTime(strip);

			if (sysConfig.enOffsetLEDs == 0 ){
					leds.setOffsetColor(strip,0,0,0);
				}
			else
			{
				if (lastUpdate < INACTIVITY_TIMEOUT)
				{
					leds.setOffsetColor(strip,0,16,0);
					globalIdle++;
				}
				else
				{
					leds.setOffsetColor(strip,16,0,0);
				}
			}
		}
		if (globalIdle == 0)
		{
			// to show the update if no channel got any data
			leds.show();
		}
	}
}

//EthernetClient client;
#ifdef USE_WEBSERVER
void webserverLoop(void)
{
  // listen for incoming clients
  EthernetClient client = server.available();
  if (client) {
	// an http request ends with a blank line
	bool currentLineIsBlank = true;
	while (client.connected()) {
	  if (client.available()) {
		char c = client.read();

		if (c == '\n' && currentLineIsBlank) {

//			 send a standard http response header
		  client.println("HTTP/1.1 200 OK");
		  client.println("Content-Type: text/html");
		  client.println("Connection: close");  // the connection will be closed after completion of the response
		  client.println("Refresh: 10");  // refresh the page automatically every 5 sec
		  client.println();
		  client.println("<!DOCTYPE HTML>");
		  client.println("<html>");

		  // output the value of each analog input pin
		  client.print("<h1>HyperLight Info </h1>");

		  client.print("My IP: ");
		  client.print(ip[0], DEC);client.print(".");
		  client.print(ip[1], DEC);client.print(".");
		  client.print(ip[2], DEC);client.print(".");
		  client.print(ip[3], DEC);

		  client.println("<br />");
		  client.print("Host: ");
		  client.print(remoteArd[0]);client.print(".");
		  client.print(remoteArd[1]);client.print(".");
		  client.print(remoteArd[2]);client.print(".");
		  client.print(remoteArd[3]);
		  client.println("<br />");
		  client.println("<br />");
		  client.println("<table border=\"1\">");

		  for (int strip = 0; strip < 16; strip++)
		  {
			client.println("<tr>");
			int lastUpdate = currentTime - leds.getUpdateTime(strip);
			client.println("<td>");
			client.print("Universe ");
			client.print(strip);
			client.println("</td>");
			client.println("<td ALIGN=\"CENTER\">");
			if (lastUpdate < INACTIVITY_TIMEOUT)
			{
				client.print("<font color=\"green\"> OK </font>");
			}
			else
			{
				client.print("<font color=\"red\"> error </font>");
			}
			client.println("</td>");
			client.println("<td>");

			client.print("updated ");
			client.print(lastUpdate);
			client.print(" ms ago ");

			client.println("</li>");
			client.println("</td>");
			client.println("</tr>");
		  }


		  client.println("</table>");
		  client.println("</html>");

//            req_index = 0;
//            StrClear(HTTP_req, REQ_BUF_SZ);
            break;
		}

		if (c == '\n') {
		  // you're starting a new line
		  currentLineIsBlank = true;
		} else if (c != '\r') {
		  // you've gotten a character on the current line
		  currentLineIsBlank = false;
		}
	  }
	}
	// give the web browser time to receive the data
	// close the connection:
	client.stop();
  }
}


#endif

#ifdef USE_OLED

void updateDisplay()
{
  static uint32_t lastDisplayUpdate = 0;
  static uint32_t lastDisplayStatus = 0;
  uint32_t displayStatus = 0;

  if(( currentTime - lastDisplayUpdate) > 1000){
	  lastDisplayUpdate = currentTime;

	  display.clearDisplay();

	  display.setCursor(0,6);
	  display.setTextColor(WHITE);
	  display.setFont(&FreeSansBold9pt7b);

	  display.print(ip[0], DEC);display.print(".");
	  display.print(ip[1], DEC);display.print(".");
	  display.print(ip[2], DEC);display.print(".");
	  display.print(ip[3], DEC);display.println("");

	  display.setFont();

	  display.setCursor(0,32);
	  display.println("|-E1-|-E2-|-E3-|-E4-|");
	  display.setCursor(0,48);

	  for (int strip = 0; strip < 16; strip++) {
		if((strip%4) == 0)
		{
			display.print("|");
		}
		int lastUpdate = currentTime - leds.getUpdateTime(strip);
		if (lastUpdate < INACTIVITY_TIMEOUT)
		{
			display.print("O");
			displayStatus |= (1<<strip);
		}
		else
		{
			display.print("X");
		}
	  }
	  display.print("|");

	  display.setCursor(0,16);
	  display.print("Host:");

	  if(displayStatus == 0)
	  {
		  display.print("*.*.*.*");
	  }
	  else
	  {
		  display.print(artnet.remote[0]);display.print(".");
		  display.print(artnet.remote[1]);display.print(".");
		  display.print(artnet.remote[2]);display.print(".");
		  display.print(artnet.remote[3]);
	  }

	  if((displayStatus != lastDisplayStatus) || (displayStatus == 0))
	  {
		  // only update if something changed
		  // update causes a flicker
		  lastDisplayStatus = displayStatus;
		  display.display();
	  }
  }
}

#endif


#ifdef USE_LCD
void updateDisplay()
{
  static uint32_t lastDisplayUpdate = 0;
  //static uint32_t lastDisplayStatus = 0;
  //uint32_t displayStatus = 0;

  if(( currentTime - lastDisplayUpdate) > 2000){
	  lastDisplayUpdate = currentTime;

	  lcd.setCursor(0, 0);
	  lcd.print(ip[0], DEC);lcd.print(".");
	  lcd.print(ip[1], DEC);lcd.print(".");
	  lcd.print(ip[2], DEC);lcd.print(".");
	  lcd.print(ip[3], DEC);lcd.print("");
	  lcd.print("  ");

	  lcd.setCursor(0, 1);
	  for (int strip = 0; strip < 16; strip++)
	  {
		int lastUpdate = currentTime - leds.getUpdateTime(strip);

		if (lastUpdate < INACTIVITY_TIMEOUT)
		{
			lcd.print("O");
		}
		else
		{
			lcd.print("X");
		}
	  }

	  lcd.display();
  }
}

#endif


#ifdef USE_FLASH

#define FLASH_ADDR 1

#endif






uint16_t configAddress = 0;

void readConfig()
{
	//flash.readAnything(FLASH_ADDR, sysConfig);
#ifdef USE_EEPROM
	EEPROM.get(configAddress, sysConfig);
#endif
#ifdef USE_FLASH
	flash.readAnything(FLASH_ADDR, sysConfig);
#endif

	if(sysConfig.valid != 42)
	{
		Serial.println("\r\nno valid flash config!");
		defaultConfig();
	}
	else
	{
		Serial.println("valid flash config");
	}

	for ( int i = 0; i < LED_LINES; i++)
	{
	    leds.setOffset(i,sysConfig.ledConfig[i].offset);
	}
}


void saveConfig()
{
#ifdef USE_EEPROM
	//flash.eraseSection(FLASH_ADDR, sizeof(sysConfig));
	//flash.writeAnything(FLASH_ADDR, sysConfig);
	Serial.println("save config!");
	EEPROM.put(configAddress, sysConfig);
	EEPROM.commit();
#endif
#ifdef USE_FLASH
	flash.eraseSection(FLASH_ADDR, sizeof(sysConfig));
	flash.writeAnything(FLASH_ADDR, sysConfig);
#endif
}


void defaultConfig()
{
	Serial.println("setup default config!");

	struct sConfig dConfig;
	sysConfig = dConfig;
	sysConfig.valid = 42;
	saveConfig();
}

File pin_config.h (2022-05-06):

/*
 * pin_config.h
 *
 *  Created on: 24.11.2019
 *      Author: ahoel
 */

#ifndef PIN_CONFIG_H_
#define PIN_CONFIG_H_




// D1 = Power
#define LED_BUILTIN_D2 PA6  // note LED overlaps with hardware SPI-1 ENC_MISO_PIN
#define LED_BUILTIN_D3 PA7  // note LED overlaps with hardware SPI-1 ENC_MOSI_PIN

// W5500 Ethernet
// HW-SPI-3 or HW_SPI-1
#define ETH_MOSI_PIN  PB5
#define ETH_MISO_PIN  PB4
#define ETH_SCK_PIN   PB3
#define ETH_SCS_PIN   PA15
#define ETH_INT_PIN   PB8
#define ETH_RST_PIN   PD3




/* UART2 To DMX IN/OUT	*/
//#define UART2_TX_PIN  PD5	// TO MAX481 DI	- tx data in
//#define UART2_RX_PIN  PD6	// TO MAX481 RO - rx data out
//#define UART2_DE_PIN  PD7	// TO MAX481 DE - data direction
//#define UART2_RE_PIN  PD4	// TO MAX481 RE - Recieve nEnable
//// for RX RE LOW,  DE LOW
//// for TX RE HIGH, DE HIGH


/* HW-SPI-2 6-Pin Header	*/
/* +5V */
#define SPI2_CS_PIN    PB12
#define SPI2_SCK_PIN   PB13
#define SPI2_MISO_PIN  PC2
#define SPI2_MOSI_PIN  PC3
/* GND */


/* HW-SPI-3 6-Pin Header	*/
/* +5V */
#define SPI3_CS_PIN    PA4
#define SPI3_CLK_PIN   PA5
#define SPI3_MOSI_PIN  PA7
#define SPI3_MISO_PIN  PA6
/* GND */


/* UART1 4-Pin Header	*/
/* +5V */
#define UART1_RX_PIN  PA10
#define UART1_TX_PIN  PA9
/* GND */

/* UART3 4-Pin Header	*/
/* +5V */
#define UART3_RX_PIN  PD9
#define UART3_TX_PIN  PD8
/* GND */

/* I2C1 4-Pin Header	*/
/* +5V */
#define I2C1_SDA_PIN  PB7
#define I2C1_SCL_PIN  PB6
/* GND */

/* I2C2 4-Pin Header	*/
/* +5V */
#define I2C2_SDA_PIN  PB11
#define I2C2_SCL_PIN  PB10
/* GND */

/* Onbaord Flash		*/
// W25Q16JV
// https://stm32-base.org/boards/STM32F407VET6-STM32-F4VE-V2.0.html
#define SPI_FLASH_CS	PB0
#define SPI_FLASH_DO	PB4
//#define SPI_FLASH_WP	+3V3
#define SPI_FLASH_DI	PB5
#define SPI_FLASH_CLK	PB3
//#define SPI_FLASH_HOLD +3V3

/* SD-Card Pins  		*/
// to do


/* Override Board SPI mappings so Ethernet is on SPI1 defined as WEAK in board file*/
const PinMap PinMap_SPI_MOSI[] = {
  {PA_7,  SPI1, STM_PIN_DATA(STM_MODE_AF_PP, GPIO_PULLUP, GPIO_AF5_SPI1)},
  {PB_5,  SPI1, STM_PIN_DATA(STM_MODE_AF_PP, GPIO_PULLUP, GPIO_AF5_SPI1)},
  {PB_5,  SPI3, STM_PIN_DATA(STM_MODE_AF_PP, GPIO_PULLUP, GPIO_AF6_SPI3)},
  {PB_15, SPI2, STM_PIN_DATA(STM_MODE_AF_PP, GPIO_PULLUP, GPIO_AF5_SPI2)},
  {PC_3,  SPI2, STM_PIN_DATA(STM_MODE_AF_PP, GPIO_PULLUP, GPIO_AF5_SPI2)},
  {PC_12, SPI3, STM_PIN_DATA(STM_MODE_AF_PP, GPIO_PULLUP, GPIO_AF6_SPI3)},
  {NC,    NP,    0}
};

 const PinMap PinMap_SPI_MISO[] = {
  {PA_6,  SPI1, STM_PIN_DATA(STM_MODE_AF_PP, GPIO_PULLUP, GPIO_AF5_SPI1)},
  {PB_4,  SPI1, STM_PIN_DATA(STM_MODE_AF_PP, GPIO_PULLUP, GPIO_AF5_SPI1)},
  {PB_4,  SPI3, STM_PIN_DATA(STM_MODE_AF_PP, GPIO_PULLUP, GPIO_AF6_SPI3)},
  {PB_14, SPI2, STM_PIN_DATA(STM_MODE_AF_PP, GPIO_PULLUP, GPIO_AF5_SPI2)},
  {PC_2,  SPI2, STM_PIN_DATA(STM_MODE_AF_PP, GPIO_PULLUP, GPIO_AF5_SPI2)},
  {PC_11, SPI3, STM_PIN_DATA(STM_MODE_AF_PP, GPIO_PULLUP, GPIO_AF6_SPI3)},
  {NC,    NP,    0}
};

const PinMap PinMap_SPI_SCLK[] = {
  {PA_5,  SPI1, STM_PIN_DATA(STM_MODE_AF_PP, GPIO_PULLUP, GPIO_AF5_SPI1)},
  {PB_3,  SPI1, STM_PIN_DATA(STM_MODE_AF_PP, GPIO_PULLUP, GPIO_AF5_SPI1)},
  {PB_3,  SPI3, STM_PIN_DATA(STM_MODE_AF_PP, GPIO_PULLUP, GPIO_AF6_SPI3)},
  {PB_10, SPI2, STM_PIN_DATA(STM_MODE_AF_PP, GPIO_PULLUP, GPIO_AF5_SPI2)},
  {PB_13, SPI2, STM_PIN_DATA(STM_MODE_AF_PP, GPIO_PULLUP, GPIO_AF5_SPI2)},
  {PC_10, SPI3, STM_PIN_DATA(STM_MODE_AF_PP, GPIO_PULLUP, GPIO_AF6_SPI3)},
  {NC,    NP,    0}
};


const PinMap PinMap_SPI_SSEL[] = {
  {PA_4,  SPI1, STM_PIN_DATA(STM_MODE_AF_PP, GPIO_PULLUP, GPIO_AF5_SPI1)},
  //  {PA_4,  SPI3, STM_PIN_DATA(STM_MODE_AF_PP, GPIO_PULLUP, GPIO_AF6_SPI3)},
  {PA_15, SPI1, STM_PIN_DATA(STM_MODE_AF_PP, GPIO_PULLUP, GPIO_AF5_SPI1)},
  {PA_15, SPI3, STM_PIN_DATA(STM_MODE_AF_PP, GPIO_PULLUP, GPIO_AF6_SPI3)},
  {PB_9,  SPI2, STM_PIN_DATA(STM_MODE_AF_PP, GPIO_PULLUP, GPIO_AF5_SPI2)},
  {PB_12, SPI2, STM_PIN_DATA(STM_MODE_AF_PP, GPIO_PULLUP, GPIO_AF5_SPI2)},
  {NC,    NP,    0}
};


#endif /* PIN_CONFIG_H_ */

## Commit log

2019-11-18 dma scheint zu funktionieren
2019-11-22 oled und webserver working
2019-11-24 pin_config.h und readme.md
2019-11-24 Added Hardware
    [HyperLight_S_rev1.0.brd, HyperLight_S_rev1.0.sch]
2020-11-29 added Pin Config file and other improvements
2020-12-23 added SPI override to map Ethernet on SPI1 instead of SPI3 since SPI1 is able to 42MBit/s and SPI3 only 22MBit/s
2020-12-29 added STM32F407.svd file for debug
2020-12-29 added check if dma is idle
2020-12-29 avoid delay in loop
    [hyperlight_dma_sloeber.ino]
2021-01-02 add support for artsync and seq based frame loss detection
2021-01-11 add spi hal code override
2022-05-06 DMA DMX output first working version
2022-06-16 added config parameter to enable/disable offset led status
2022-06-16 status leds are working now
